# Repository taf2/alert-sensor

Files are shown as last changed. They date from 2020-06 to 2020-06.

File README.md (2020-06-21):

# Get a chim when someone enters the driveway

Using a combination of Trinket M0, a IR light break sensor, nrf24l01 radios and a raspberry PI to receive a ding dong when someone walks or drives into the drive way

We will play music when someone or something breaks the light beam which should indicate they have entered the driveway

Because we're using Trinket M0 outside in the driveway and it has limited pins to transmit and also respond to a 
light break sensor GPIO pin we need two Trinket M0's.   We also have batteries so we'll be using verters from adafruit.
IMO these are nice beause they both boost and buck voltage while not being as good of a boost they serve both use cases
well so we'll be able to use a feature of the buck/boost converter to power on/off another Trinket M0 that will when activated
send our signal to our home Trinket that will activate this program running on our raspberry PI 3 B+ to play some music chims

*Note we could simplify our setup with a bigger micro controller that would combine irbreak.ino and transmitter.ino two trinkets into 1 but I could not figure out away to send message without using all available trinket pins*

Part 1 - https://youtu.be/JmLufwKJ6Tg (demo of the setup working with bread boards)

# IR break beam sensor - trinket m0 
see: irbreak.ino
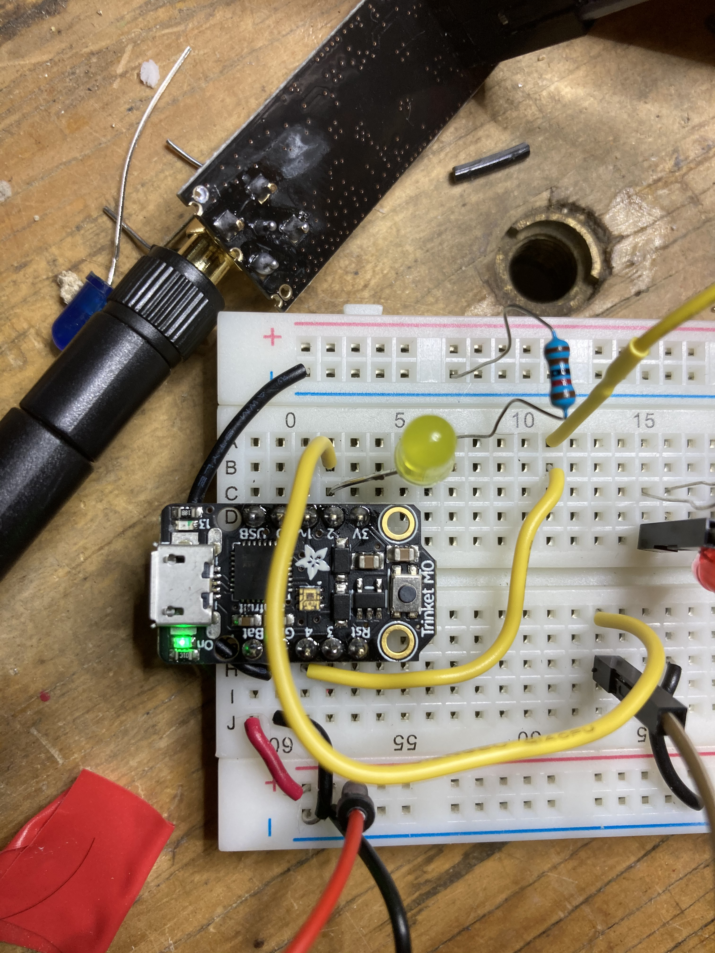
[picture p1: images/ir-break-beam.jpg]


Job is to enable power to trinket transmitter when pin 4 is low

PIN 4 - yellow wire from break beam sensor when LOW the beam is broken
PIN 2 - attached to enable pin on Boost/Buck converter
GND   - common ground connected to break beam sensor and power source (very important otherwise it will never go low)
BAT   - connected to postive battery

# Wiring nRF24L01 to trinkets
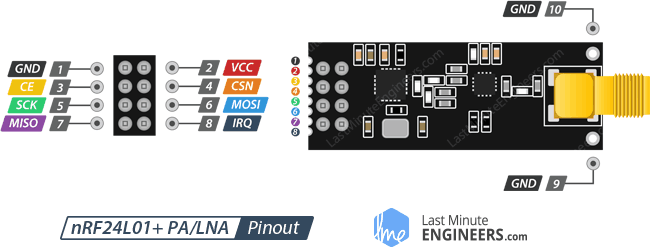
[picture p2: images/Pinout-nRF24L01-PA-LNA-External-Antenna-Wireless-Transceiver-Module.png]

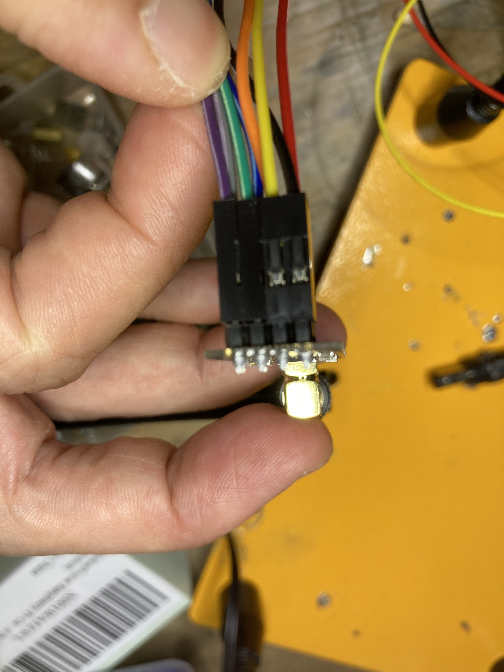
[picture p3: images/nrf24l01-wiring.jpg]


```
[YELLOW] - CE (Chip Enable) is an active-HIGH pin. When selected the nRF24L01 will either transmit or receive, depending upon which mode it is currently in.
[ORANGE] - CSN (Chip Select Not) is an active-LOW pin and is normally kept HIGH. When this pin goes low, the nRF24L01 begins listening on its SPI port for data and processes it accordingly.
[GREEN]  - SCK (Serial Clock) accepts clock pulses provided by the SPI bus Master.
[BLUE]   - MOSI (Master Out Slave In) is SPI input to the nRF24L01.
[PURPLE] - MISO (Master In Slave Out) is SPI output from the nRF24L01.
[GREY]   - IRQ is an interrupt pin that can alert the master when new data is available to process.
```

# transmitter - trinket m0 nRF24L01

see: transmitter.ino
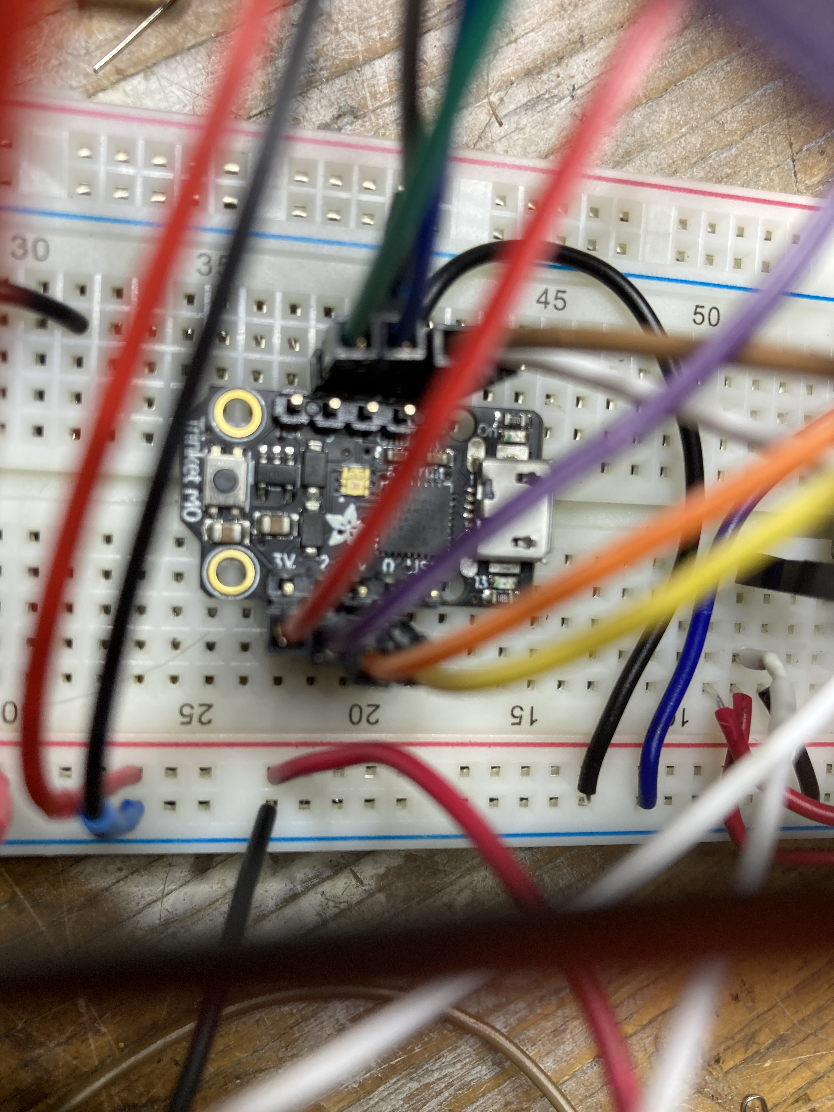
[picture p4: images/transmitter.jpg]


Job is to send a message when power is on.  For usage of nrf24l01 see https://lastminuteengineers.com/nrf24l01-arduino-wireless-communication/

PIN 0 - yellow wire
PIN 1 - orange wire
PIN 2 - purple wire
PIN 3 - green wire
PIN 4 - blue wire
GND
BAT

# receiver - trinket m0 nRF24L01
*Note, i did not need to attach the grey wire in both transmitter or receiver.   On the receiver we seem to be able to get away with not attaching the yellow wire - this frees up one pin for signaling our pi*

see: receiver.ino
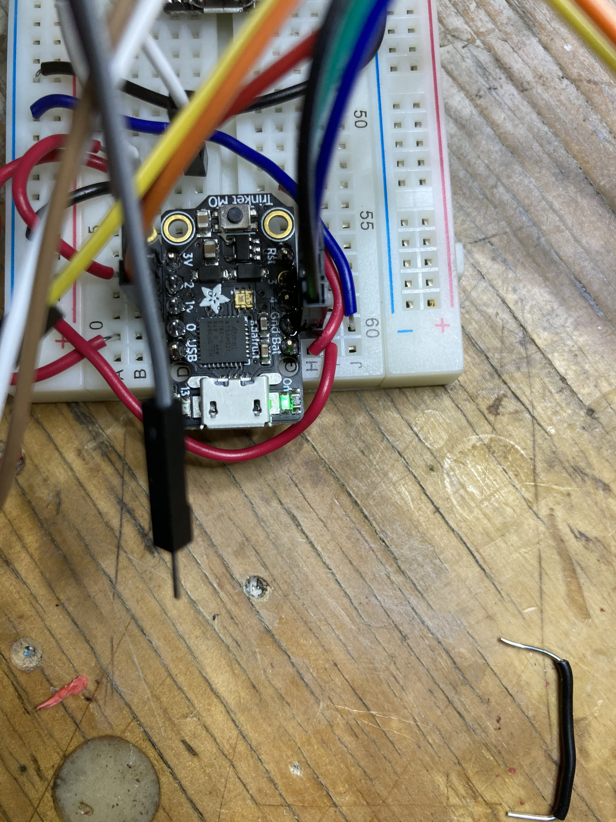
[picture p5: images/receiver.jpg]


PIN 0 - signal wire (not the yellow wire pin held high and goes low when we received a signal)
PIN 1 - orange wire
PIN 2 - purple wire
PIN 3 - green wire
PIN 4 - blue wire
GND
BAT

# chim player - raspberry pi

see play.c
see: https://lauri.xn--vsandi-pxa.com/2013/12/implementing-mp3-player.en.html
be sure to install audio libraries
```
sudo apt install libmad0-dev libpulse-dev pulseaudio
# and run the pulseaudio daemon
pulseaudio -D
```
*Note doorbell.mp3 is located in the checkout directory which in my case is /home/pi/alert-sensor/doorbell.mp3 anywhere else and you will need to modify play.c*

PIN 36 - held HIGH unless we need to play music chim
PIN 34 - GND for led indicator
PIN 32 - held LOW unless we need to blink the led because of a break in our sensor beam detected

Attaching the raspberry pi to a speaker and play an mp3

# case fitting
For the remote IR sensor and transmitter I'm using a PVC Conduit  L connector.   I [3d printed an antenna cap](parts/antenna-fitting.stl) to plug one of the 
holes for the antenna to sit securely.   On the other open hole I [3d printed another block](parts/ir-sensor-mount.stl) with a cut away for the IR sensor.
I drilled a small 3/4 in hole into the side of the PVC to run a power wire and secured it with a little bit of extra shrink wrap.

See: https://www.homedepot.com/p/Carlon-1-2-in-Schedule-40-and-80-PVC-Type-LB-Conduit-Body-Case-of-20-E986D-CTN/202205910

# power setup

To power the remote setup I don't have good power from my driveway nor do I want to dig it up to run power lines. So solar is a 
nice option and hopefully will allow this project to run for a very long time without having to replace batteries.  To do this
I use adafruit lipo charger learn more here: https://learn.adafruit.com/usb-dc-and-solar-lipoly-charger/using-the-charger

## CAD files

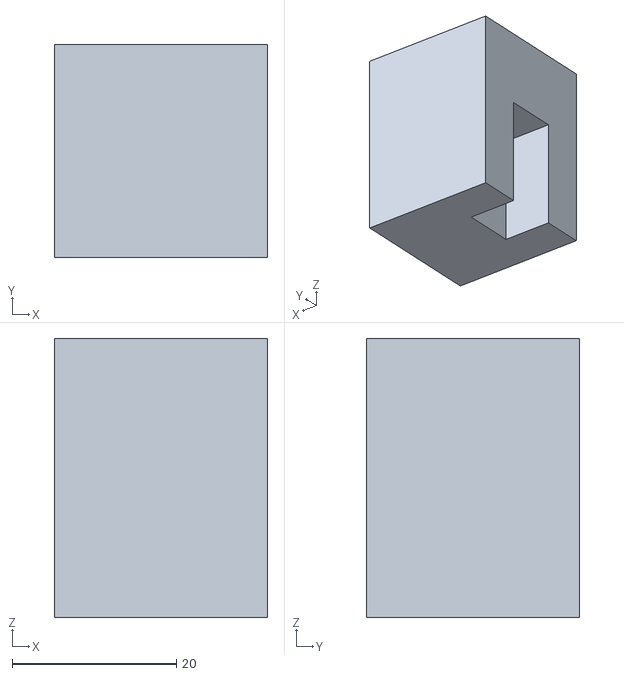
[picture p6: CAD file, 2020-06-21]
parts/ir-sensor-mount.stl
26.0 x 26.0 x 34.0

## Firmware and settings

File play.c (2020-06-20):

/*
 * Attached to our trinket m0 GPIO PIN
 */

#include <stdio.h>
#include <stdlib.h>
#include <string.h>
#include <time.h>
#include <signal.h>
#include <unistd.h>

#include <sys/stat.h>
#include <sys/mman.h>
#include <mad.h>
#include <pulse/simple.h>
#include <pulse/error.h>

#include <wiringPi.h>

#define DELAY_BETWEEN_ALARM 15 // how long to wait before double alarm

#define ALERT_PIN 36
#define INDICATOR_PIN 32  

pa_simple *device = NULL;
int ret = 1;
int error;
struct mad_stream mad_stream;
struct mad_frame mad_frame;
struct mad_synth mad_synth;

void output(struct mad_header const *header, struct mad_pcm *pcm);

// see: https://lauri.xn--vsandi-pxa.com/2013/12/implementing-mp3-player.en.html
int playDoorChim() {
  // Set up PulseAudio 16-bit 44.1kHz stereo output
	static const pa_sample_spec ss = { .format = PA_SAMPLE_S16LE, .rate = 44100, .channels = 2 };
	if (!(device = pa_simple_new(NULL, "MP3 player", PA_STREAM_PLAYBACK, NULL, "playback", &ss, NULL, NULL, &error))) {
    printf("pa_simple_new() failed\n");
    return 255;
	}

	// Initialize MAD library
	mad_stream_init(&mad_stream);
	mad_synth_init(&mad_synth);
	mad_frame_init(&mad_frame);

	// Filename pointer
	char *filename = "/home/pi/alert-sensor/doorbell.mp3";

	// File pointer
	FILE *fp = fopen(filename, "r");
	int fd = fileno(fp);

	// Fetch file size, etc
	struct stat metadata;
	if (fstat(fd, &metadata) >= 0) {
    printf("File size %d bytes\n", (int)metadata.st_size);
	} else {
    printf("Failed to stat %s\n", filename);
    fclose(fp);
    return 254;
	}

	// Let kernel do all the dirty job of buffering etc, map file contents to memory
	const unsigned char *input_stream = mmap(0, metadata.st_size, PROT_READ, MAP_SHARED, fd, 0);

	// Copy pointer and length to mad_stream struct
	mad_stream_buffer(&mad_stream, input_stream, metadata.st_size);

  printf("start playback\n");
	// Decode frame and synthesize loop
	while (1) {
		// Decode frame from the stream
		if (mad_frame_decode(&mad_frame, &mad_stream)) {
			if (MAD_RECOVERABLE(mad_stream.error)) {
        continue;
			} else if (mad_stream.error == MAD_ERROR_BUFLEN) {
        break;
			} else {
        break;
			}
		}
		// Synthesize PCM data of frame
		mad_synth_frame(&mad_synth, &mad_frame);
		output(&mad_frame.header, &mad_synth.pcm);
	}
  printf("end playback\n");

	// Close
	fclose(fp);

	// Free MAD structs
	mad_synth_finish(&mad_synth);
	mad_frame_finish(&mad_frame);
	mad_stream_finish(&mad_stream);

	// Close PulseAudio output
	if (device) {
		pa_simple_free(device);
  }
  return EXIT_SUCCESS;
}
// Some helper functions, to be cleaned up in the future
int scale(mad_fixed_t sample) {
  /* round */
  sample += (1L << (MAD_F_FRACBITS - 16));
  /* clip */
  if (sample >= MAD_F_ONE)
    sample = MAD_F_ONE - 1;
  else if (sample < -MAD_F_ONE)
    sample = -MAD_F_ONE;
  /* quantize */
  return sample >> (MAD_F_FRACBITS + 1 - 16);
}

void output(struct mad_header const *header, struct mad_pcm *pcm) {
  register int nsamples = pcm->length;
  mad_fixed_t const *left_ch = pcm->samples[0], *right_ch = pcm->samples[1];
  static char stream[1152*4];
  if (pcm->channels == 2) {
    while (nsamples--) {
      signed int sample;
      sample = scale(*left_ch++);
      stream[(pcm->length-nsamples)*4 ] = ((sample >> 0) & 0xff);
      stream[(pcm->length-nsamples)*4 +1] = ((sample >> 8) & 0xff);
      sample = scale(*right_ch++);
      stream[(pcm->length-nsamples)*4+2 ] = ((sample >> 0) & 0xff);
      stream[(pcm->length-nsamples)*4 +3] = ((sample >> 8) & 0xff);
    }
    if (pa_simple_write(device, stream, (size_t)1152*4, &error) < 0) {
      fprintf(stderr, "pa_simple_write() failed: %s\n", pa_strerror(error));
      return;
    }
  } else {
    printf("Mono not supported!");
  }
}

static time_t lastAlarm = 0;

void setup() {

  lastAlarm = time(0) - DELAY_BETWEEN_ALARM;

  wiringPiSetupPhys();

  pinMode(ALERT_PIN, INPUT);
  pinMode(INDICATOR_PIN, OUTPUT);

}


void loop() {
  int secondsSinceLastAlarm = 0;
  time_t alarmTime = 0;

  int alert = digitalRead(ALERT_PIN);

  if (!alert) {
    alarmTime = time(0);
    secondsSinceLastAlarm = (int)difftime(alarmTime, lastAlarm);
    if (secondsSinceLastAlarm > DELAY_BETWEEN_ALARM) {
      printf("Alarm!\n");
      digitalWrite(INDICATOR_PIN, HIGH);
      lastAlarm = alarmTime;
      playDoorChim();
    } else {
      printf("Last alarmed within the same minute, %d seconds remaining.\n", (DELAY_BETWEEN_ALARM - secondsSinceLastAlarm));
      if ((secondsSinceLastAlarm % 2) == 1) {
        digitalWrite(INDICATOR_PIN, LOW);
      } else {
        digitalWrite(INDICATOR_PIN, HIGH);
      }
      delay(500);
    }
  } else {
    digitalWrite(INDICATOR_PIN, LOW);
  }

}

void cleanup(int signum, siginfo_t *info, void *ptr) {
  digitalWrite(INDICATOR_PIN, LOW);

  exit(0);
}

int main(int argc, char**argv) {
  if (argc > 1) {
    playDoorChim();
    return 0;
  }
  static struct sigaction _sigact;
  memset(&_sigact, 0, sizeof(_sigact));
  _sigact.sa_sigaction = cleanup;
  _sigact.sa_flags = SA_SIGINFO;

  sigaction(SIGINT, &_sigact, NULL);

  setup();

  puts("warming up 3 seconds...");
  delay(3000);
  puts("starting up now");

  while (1) {
    loop();
  }

  return 0;
}

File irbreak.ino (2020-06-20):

#include <Adafruit_DotStar.h>
#include <SPI.h>

#define NUMPIXELS 1
#define DATAPIN 7
#define CLOCKPIN 8

Adafruit_DotStar strip = Adafruit_DotStar(NUMPIXELS, DATAPIN, CLOCKPIN, DOTSTAR_BGR);

/* 
  IR Breakbeam sensor demo!
  from adafruit site
*/

#define ALARM 1
#define LEDPIN 2
// Pin 13: Arduino has an LED connected on pin 13
// Pin 11: Teensy 2.0 has the LED on pin 11
// Pin  6: Teensy++ 2.0 has the LED on pin 6
// Pin 13: Teensy 3.0 has the LED on pin 13
 
#define SENSORPIN 4
 
void setup() {
  strip.begin();
  strip.show(); // turns everything off
  
  // initialize the LED pin as an output:
  pinMode(LEDPIN, OUTPUT);    
  pinMode(ALARM, OUTPUT);  
  // initialize the sensor pin as an input:
  pinMode(SENSORPIN, INPUT);     
  digitalWrite(SENSORPIN, HIGH); // turn on the pullup
  digitalWrite(ALARM, HIGH);
  Serial.begin(9600);
}
 
void loop(){
  // read the state of the pushbutton value:
  const int sensorState = digitalRead(SENSORPIN);
 
  // check if the sensor beam is broken
  // if it is, the sensorState is LOW:
  if (sensorState == LOW) {     
    // turn LED on:
    digitalWrite(LEDPIN, HIGH);  
    digitalWrite(ALARM, LOW);

    Serial.println("Broken");
    
  } 
  else {
    // turn LED off:
    digitalWrite(LEDPIN, LOW); 
    digitalWrite(ALARM, HIGH);

    Serial.println("Unbroken");
  }

}

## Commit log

2020-06-20 more pictures for wiring
2020-06-20 including a video of the bread board setup
2020-06-21 Adding the stl files used to enclose the antenna and ir break beam receiver sensor
    [ir-sensor-mount.stl]
